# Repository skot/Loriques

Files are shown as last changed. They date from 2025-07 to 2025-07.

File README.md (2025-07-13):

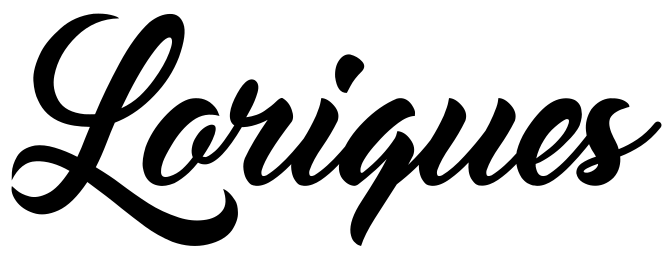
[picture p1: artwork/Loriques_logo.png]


Loriques is a solar powered Meshtastic LoRa gateway. *Warning: Loriques is very much a work in progress.*

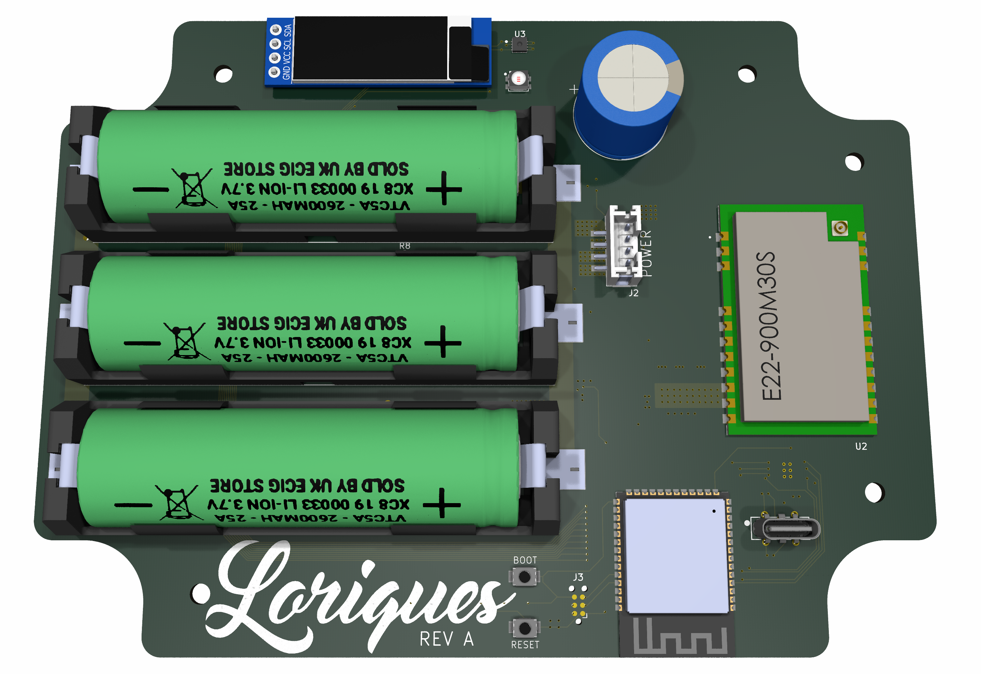
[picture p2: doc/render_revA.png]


- Designed to work with a small 6V solar panel. Like the [Voltaic 6 Watt Panel](https://voltaicsystems.com/6-watt-panel/)
- [EBYTE E22-900M30S](https://www.cdebyte.com/products/E22-900M30S/3) 30dBm LoRa tranciever
  - Untested; I picked this because it's in the Meshtastic supported LoRa ISM band, and it has one of the highest listed output power of LoRa modules.
  - Selecting a good high-gain antenna for this module is TBD.
- ESP32S3 WiFi and BLE SoC
- OLED Display
- Holders for three 18650 Lithium Ion batteries
- MCP73871 Solar charge controller
  - Optimized for solar charging and load sharing, but not a "true MPPT" controller. More info from [Adafruit](https://learn.adafruit.com/usb-dc-and-solar-lipoly-charger/design-notes)
- MAX17263 Battery fuel Guage
- HDC3020 Temperature and humidity sensor
  - This is helpful for monitoring how waterproof your outdoor enclosure is. 
- Very low noise, filtered 3.3V voltage regulator
- PCB designed to fit into the [Polycase ML-46F](https://www.polycase.com/ml-46f#ML-46F*15) Outdoor NEMA Enclosure
- ESP32 Firmware is **not** started yet!
  - There are some big challenges here, like getting the ESP32S3 and it's radios in, and out of a low power state.

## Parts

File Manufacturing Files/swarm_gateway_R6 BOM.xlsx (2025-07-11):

Qty | Part Name | PARTNO | Device | Value | Description
1 | A2 | W3012 | W3012 | W3012 | 900MHz Chip RF Antenna 902MHz ~ 928MHz 2dBi Solder Surface Mount
3 | B1 B2 B3 | 1042 | 18650_1042 | 18650_1042 | Battery Holder (Open) 18650 1 Cell SMD Tab
1 | IC11 | TCM310U | STM300_TCM300 | TCM310U | General ISM < 1GHz - Transceiver Module 902MHz Antenna Not Included Surface Mount
18 | C1 C2 C8 C9 C14 C15 C17 C20 C21 C26 C29 C30 C42 C43 C48 C50 C63 C23 | CL05B104KO5NNNC | CAP0402 | 0.1uF | 0402 Capacitor
1 | C25 | GRT155R61E474ME01D | CAP0402 | 0.47uF | 0402 Capacitor
8 | C40 C60 C69 C72 C73 C75 C76 C12 | GCM155R71H102KA37D | CAP0402 | 1nF | 0402 Capacitor
6 | C37 C39 C34 C35 C59 C61 | GRT155R61E105KE01D | CAP0402 | 1uF | 0402 Capacitor
2 | C33 C38 | CL10A105KA8NNNC | CAP0603 | 1uF | 0603 Capacitor
1 | C13 | 885012107013 | CAP0805 | 4.7uF | 0805 Capacitor
1 | C11 | CL05C100DB5NNNC | CAP0402 | 10pF C0G | 0402 Capacitor
4 | C3 C5 C6 C22 | GRM188R6YA106MA73D | CAP0603 | 10uF | 0603 Capacitor
4 | C41 C45 C46 C47 | CL31B106KOHNNWE | CAP1206 | 10uF | 1206 Capacitor
1 | C16 | 293D106X0010A2TE3 | CPOL_3216 | 10uF | Polarized SMD Capacitor 3126
4 | C4 C7 C18 C19 | CC0402FRNPO9BN220 | CAP0402 | 22pF | 0402 Capacitor
2 | C31 C44 | LMK212BBJ226MG-T | CAP0805 | 22uF | 0805 Capacitor
1 | C10 | C1005C0G1H470J050BA | CAP0402 | 47pF C0G | 0402 Capacitor
1 | C28 | C4532X5R1A476M280KA | CAP1812 | 47uF 10V | 1812 Capacitor
1 | C32 | C4532X5R0J107M280KA | CAP1812 | 100uF 6.3V | 1812 Capacitor
2 | C62 C64 | GRM32ER60J227ME05L | CAP1210 | 220uF | 1210 Capacitor
1 | C24 | CL05C681JB5NNNC | CAP0402 | 680pF C0G | 0402 Capacitor
1 | DISP1 | SAM1213-04-ND |  | SSW-104-01-T-S | 4 pin 0.1" female header
1 | C27 | 25PK4700MEFC16X25 | CPOL_16X27MM | 4700uF | 4700µF 25V Aluminum Electrolytic Capacitors Radial
1 | D1 | MBR120VLSFT1G | MBR120VLSF | MBR120VLSF | SOD-123F SMD Schottky Diode
2 | D2 D3 | SMAJ5.0A | SMAJ5.0A | SMAJ5.0A | 9.2V Clamp 43.5A Ipp Tvs Diode Surface Mount DO-214AC (SMA)
2 | FL2 FL3 | YFF31HC2A104MT000N | YFF31HC2A104MT000N | YFF31HC2A104MT000N | 0.1µF Feed Through Capacitor 100V 10A 1.5mOhm 1206 (3216 Metric), 4 PC Pad
1 | FL1 | YFF31HC2A105MT000N | YFF31HC2A105MT000N | YFF31HC2A105MT000N | Feed Through Capacitor 100V 5mOhm 1206 (3216 Metric), 4 PC Pad
1 | IC5 | CAT25160VI-GT3 | CAT25160VI-GT3 | CAT25160VI-GT3 | EEPROM Memory IC 16Kb (2K x 8) SPI 20MHz 8-SOIC
1 | IC3 | HDC2080DMBR | HDC2080 | HDC2080 | Humidity Temperature Sensor 0 ~ 100% RH I¬≤C ±2% RH 8s Surface Mount
1 | IC7 | LP38693MP-ADJ | LP38691-ADJ | LP38691-ADJ | LP38693-ADJ Voltage Regulator
1 | IC9 | LTC3113EDHD#TRPBF | LTC3113 | LTC3113 | Buck-Boost Switching Regulator IC Positive Adjustable 1.8V 1 Output 3A 16-WFDFN Exposed Pad
1 | IC10 | MAX17263LETD+T | MAX17263LETD+T | MAX17263LETD+T | Single/Multi-Cell Fuel Gauge with ModelGauge m5 EZ and Integrated LED Control
1 | IC2 | MCP73871-2CCI/ML | MCP73871 | MCP73871 | Microchip Li Battery Charge controller
1 | IC1 | MSP432P401RIPZR | MSP432 | MSP432P401R | ARM Cortex-M4F MSP432 Microcontroller IC 32-Bit 48MHz 256KB (256K x 8) FLASH 100-LQFP (14x14)
2 | IC6 IC8 | SN74LVC244ARGY | SN74LVC244A | SN74LVC244A | SN74LVC244A Buffer, Non-Inverting 2 Element 4 Bit per Element Push-Pull Output 20-VQFN (3.5x4.5)
1 | IC4 | TPS2013AD | TPS2013A | TPS2013A | IC 2.2A POWER DIST SWITCH 8-SOIC
3 | IC12 IC13 IC19 | TPS22975DSGR | TPS22975 | TPS22975 | TPS22975LOAD SWITCH N-CH 6A 8WSON
1 | IC14 | AT25QF641B-SHB-T | AT25QF641B-SHB-T | AT25QF641B-SHB-T | FLASH - NOR Memory IC 64Mb (8M x 8) SPI 104MHz 8-SOIC
1 | J2 | B-PH-SM4-TB(LF)(SN) | JST_4PIN | JST_4PIN | Connector Header Surface Mount 4 position 0.079" (2.00mm)
1 | J1 | B3B-PH-SM4-TB(LF)(SN) | JST_PH_3PIN | JST_PH_3PIN | Connector Header Surface Mount 3 position 0.079" (2.00mm)
1 | L1 | HCMA0703-2R2-R | HCMA0703-2R2-R | 2.2uH | 2.2µH Shielded Wirewound Inductor 8A 20mOhm Max Nonstandard
1 | L2 | LQM21PN4R7NGRD | LQM2MP_G0 | 4.7uH | 4.7µH Shielded Multilayer Inductor 800mA 288 mOhm Max 0805
1 | L3 | 742863160 | FERRITE_0603 | FERRITE | 0603 Ferrite bead
3 | LED0 LED1 LED2 | CLV1A-FKB-CK1VW1DE1BB7C3C3 | CLV1L-FKB | CLV1A-FKB | Red, Green, Blue (RGB) 622nm Red, 529nm Green, 469nm Blue LED Indication - Discrete 2V Red, 3.2V Green, 3.2V Blue 4-LCC (J-Lead)
1 | Q1 | FC-135R 32.7680KA-A3 | CRYSTALLF_GENERAL | 32kHz
1 | Q2 | FA-238 48.0000MB-K3 | FA-238-ALLEPSON_FA-238 | 48MHz
3 | R1 R21 R23 | RMCF0402ZT0R00 | RESISTOR0402-RES | 0 | 0402 Resistor
1 | R37 | RC0402FR-071K1L | RESISTOR0402-RES | 1.1k | 0402 Resistor
1 | R15 | RC0402FR-071K54L | RESISTOR0402-RES | 1.54k | 0402 Resistor
1 | R39 | CRCW04021M00FKEDC | RESISTOR0402-RES | 1M | 0402 Resistor
1 | R11 | RC0402FR-071KL | RESISTOR0402-RES | 1k | 0402 Resistor
1 | R3 | RMCF0402FT6K49 | RESISTOR0402-RES | 6.49k | 0402 Resistor
7 | R24 R25 R48 R49 R18 R19 R20 | RC0402FR-0710KL | RESISTOR0402-RES | 10k | 0402 Resistor
1 | R8 | ERT-J0EM103J | RESISTOR0402-RES | 10k NTC | 0402 Resistor
1 | R36 | PCS1206DR0100ET | RESISTOR1206 | 10m 0.5% | 1206 Resistor
6 | R16 R17 R26 R27 R28 R29 | CRGCQ0402J22R | RESISTOR0402-RES | 22 | 0402 Resistor
1 | R4 | ERJ-2RKF4702X | RESISTOR0402-RES | 47k | 0402 Resistor
1 | R7 | RC0402FR-0749K9L | RESISTOR0402-RES | 49.9k | 0402 Resistor
1 | R14 | RC0402FR-0769K8L | RESISTOR0402-RES | 69.8k | 0402 Resistor
1 | R2 | ERA-6AEB913V | RESISTOR0805-RES | 91K | 0.1%, 25ppm/C 0805 Resistor
6 | R5 R12 R13 R32 R33 R40 | RC0402FR-07100KL | RESISTOR0402-RES | 100k | 0402 Resistor
1 | R10 | RC0402FR-07113KL | RESISTOR0402-RES | 113k | 0402 Resistor
2 | R34 R35 | RMCF0402FT182K | RESISTOR0402-RES | 182k | 0402 Resistor
3 | R22 R30 R31 | CRGCQ0402F270R | RESISTOR0402-RES | 270 | 0402 Resistor
1 | R38 | RC0402FR-07330RL | RESISTOR0402-RES | 330 | 0402 Resistor
1 | R9 | RC0402JR-07330KL | RESISTOR0402-RES | 330k | 0402 Resistor
1 | R6 | RC0402FR-07825KL | RESISTOR0402-RES | 825k | 0402 Resistor
1 | S2 | MK24-A-2 | MK24-A-2 | MK24-A-2 | Molded Body Reed Switch SPST-NO 22 ~ 55AT Operate Range 1W 100mA (AC/DC) Surface Mount
1 | S1 | MS288-10F | MS288-10F | MS288-10F | RF Shield Frame 0.764" (19.40mm) X 1.134" (28.80mm) - Solder
1 | S1-2 | MS288-10C | MS288-10C | MS288-10C | Metal shield cover for MS288-10F. Snap onto S1
1 | IC15 | Swarm Tile - Consign | TILE_V3 | TILE_V3 | Swarm Tile V3 SMD Module - SweetSense consign

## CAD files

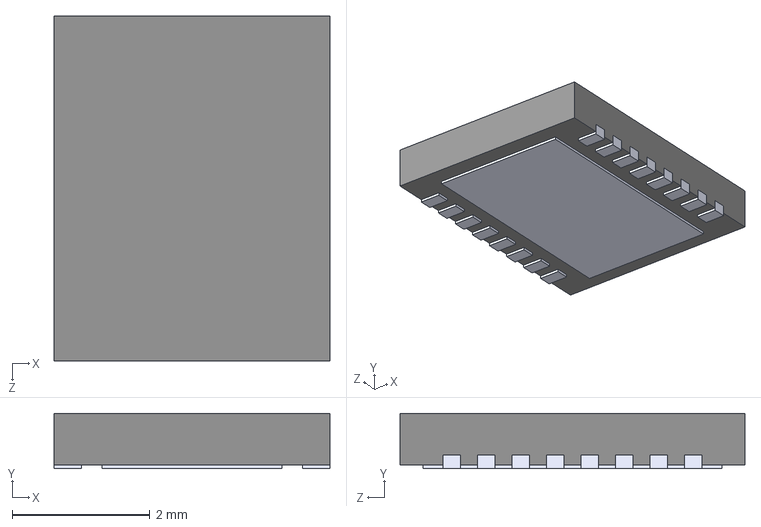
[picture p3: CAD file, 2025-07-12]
3d/LTC3113IDHD_TRPBF.step
4.00 x 0.8 x 5.00 mm

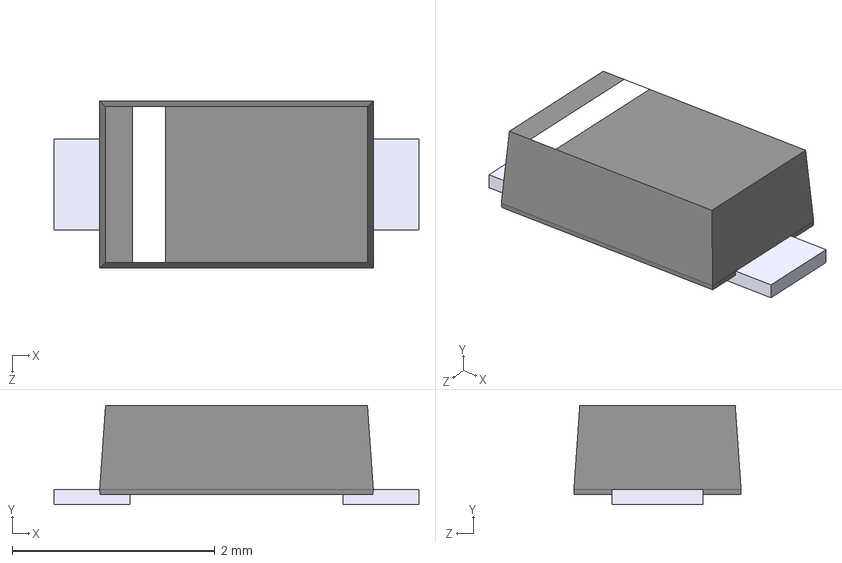
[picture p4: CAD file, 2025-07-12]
3d/MBR120VLSFT1G.step
3.60 x 0.98 x 1.65 mm

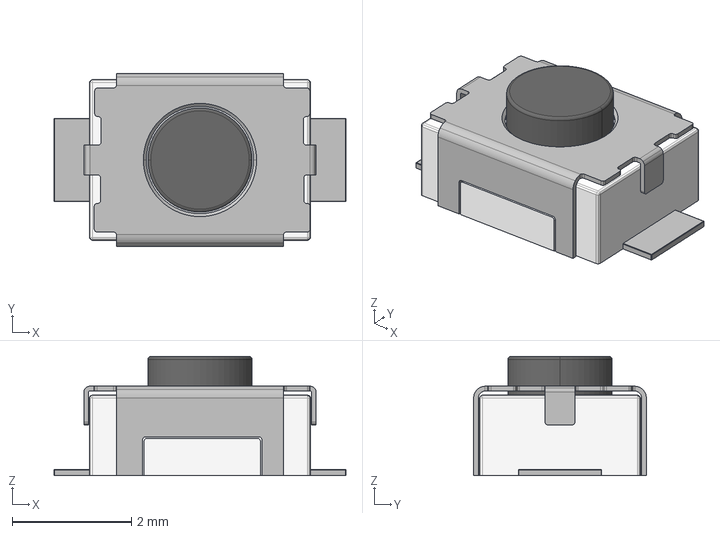
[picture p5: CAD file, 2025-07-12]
3d/CS1213AG-tr.stp
4.90 x 2.90 x 2.00 mm

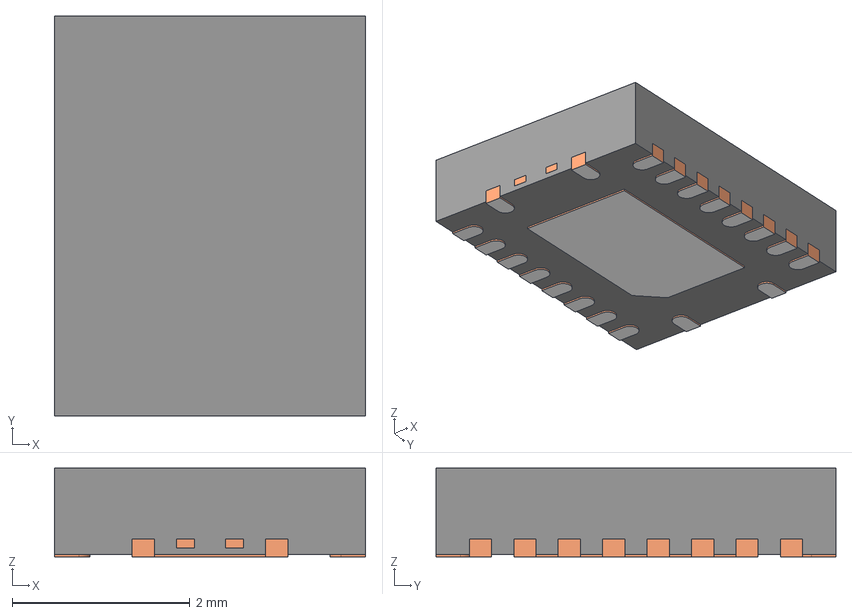
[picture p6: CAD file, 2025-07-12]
3d/RGY0020A.stp
3.50 x 4.50 x 1.00 mm
BODY-QFN
FRAME-RGY0020A
PIN1-ID

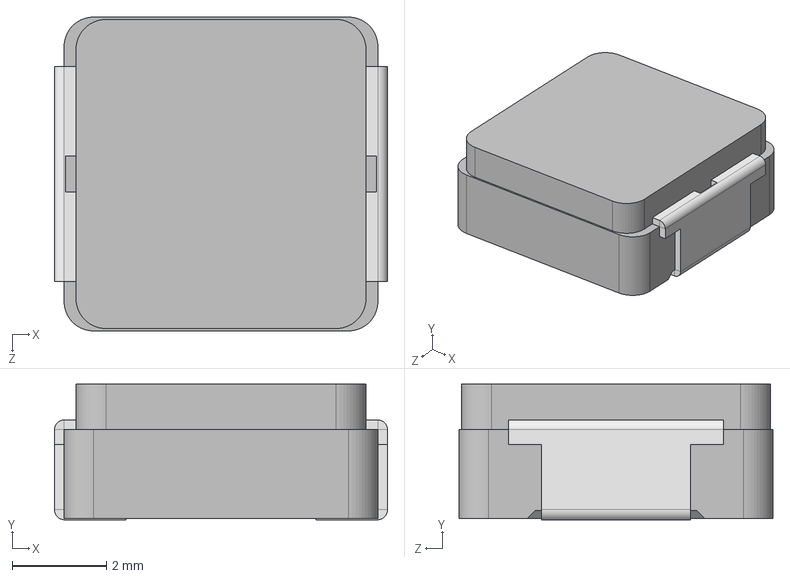
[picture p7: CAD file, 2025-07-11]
3d/IHLP2525CZ.step
7.08 x 2.88 x 6.67 mm

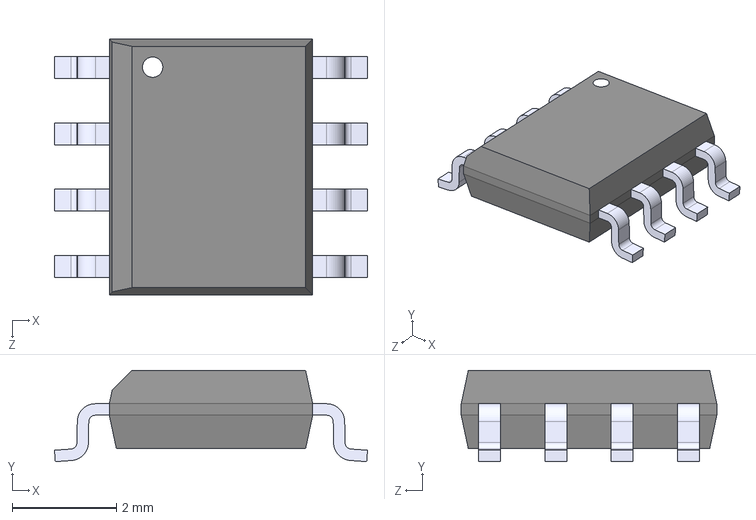
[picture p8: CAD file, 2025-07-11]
3d/TPS2013AD.step
6.00 x 1.75 x 4.90 mm

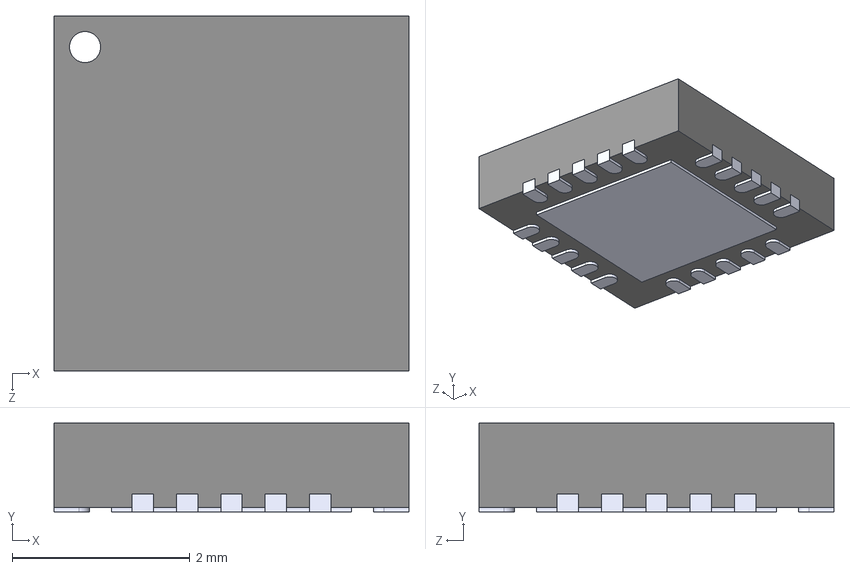
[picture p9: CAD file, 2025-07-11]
3d/ML.STEP
4.00 x 1.00 x 4.00 mm

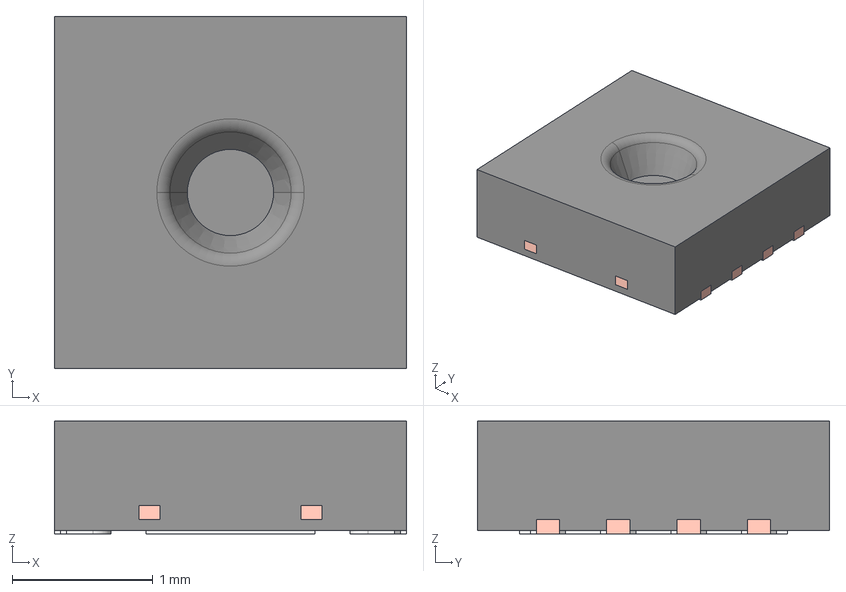
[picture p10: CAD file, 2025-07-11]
3d/DEF0008A.stp
2.50 x 2.50 x 0.8 mm
BODY-SON
FRAME-DEF0008A
PIN1-ID
SENSOR_AREA

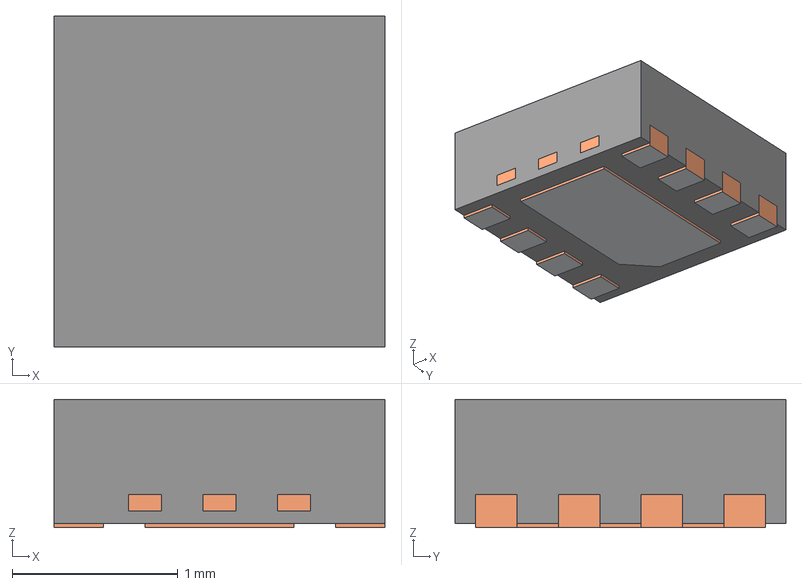
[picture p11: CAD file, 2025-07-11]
3d/DSG0008A.stp
2.00 x 2.00 x 0.775 mm
BODY-SON
FRAME-DSG0008A
PIN1-ID

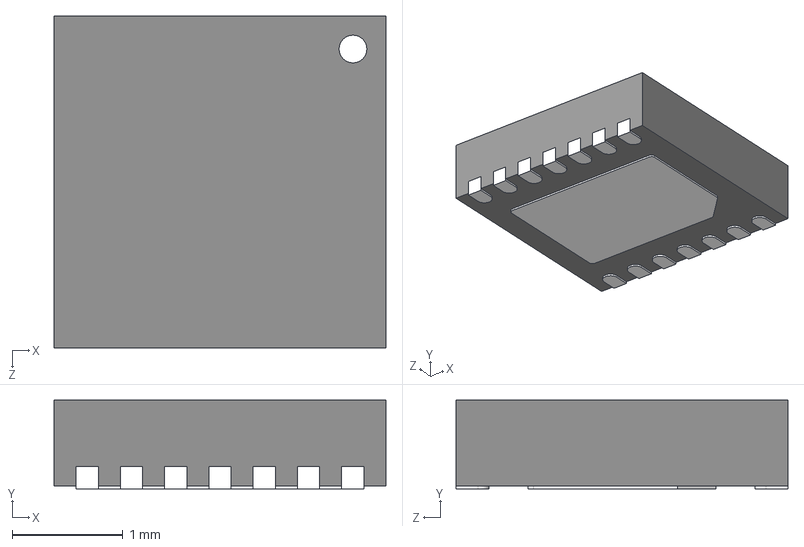
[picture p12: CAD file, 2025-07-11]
3d/SON40P300X300X80-15N.step
3.00 x 0.8 x 3.00 mm

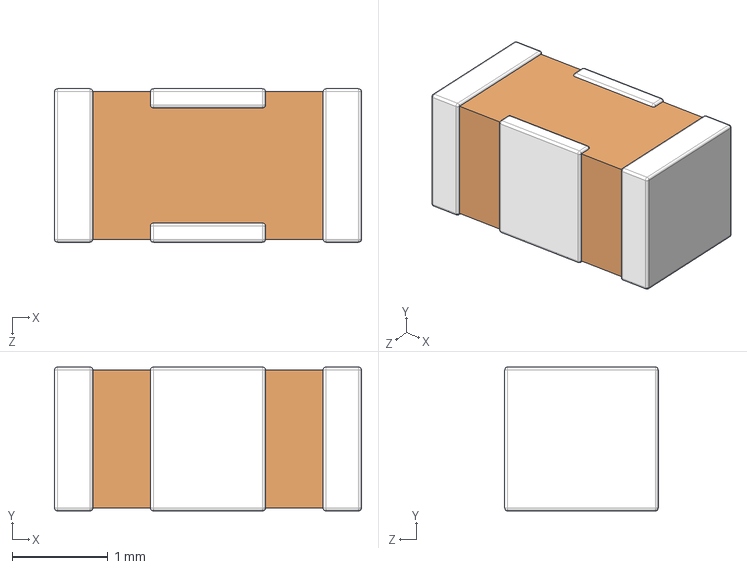
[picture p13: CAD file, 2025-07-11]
3d/YFF31HC2A105MT000N.step
3.20 x 1.50 x 1.60 mm

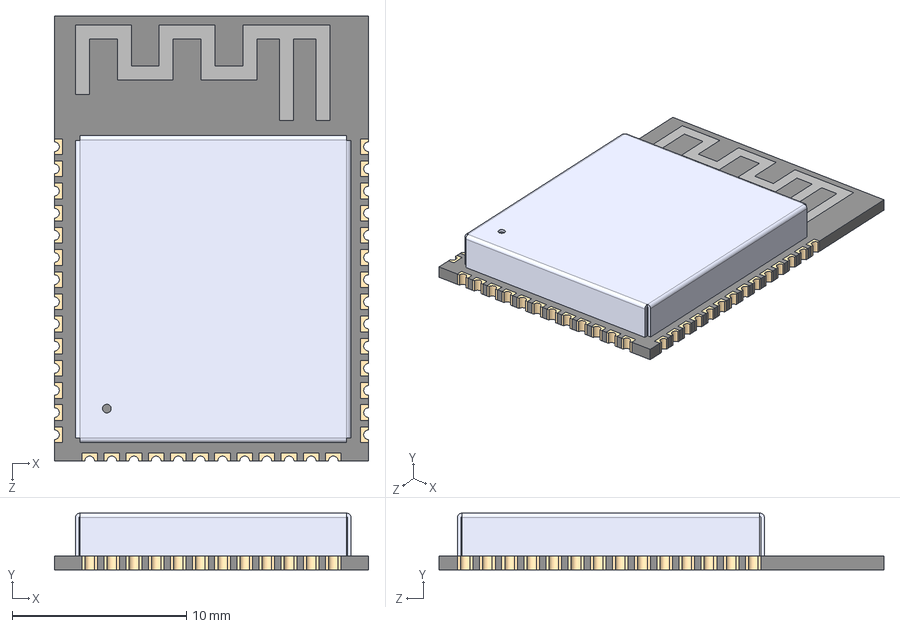
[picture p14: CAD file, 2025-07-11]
3d/ESP32-S3-WROOM-1-N8R2--3DModel-STEP-56544.STEP
18.0 x 3.25 x 25.5 mm

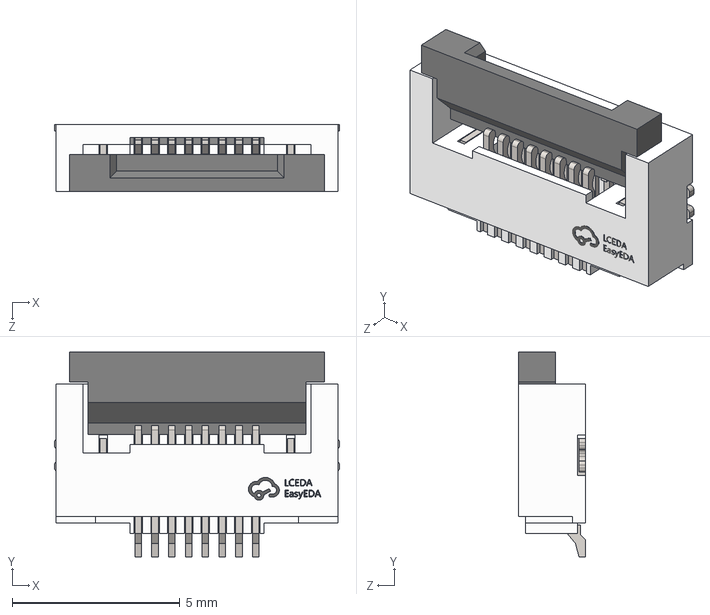
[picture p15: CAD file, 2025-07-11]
3d/FPC-SMD_P0.50-8P_FGS-XJ-H2.0.step
8.50 x 6.10 x 2.01 mm

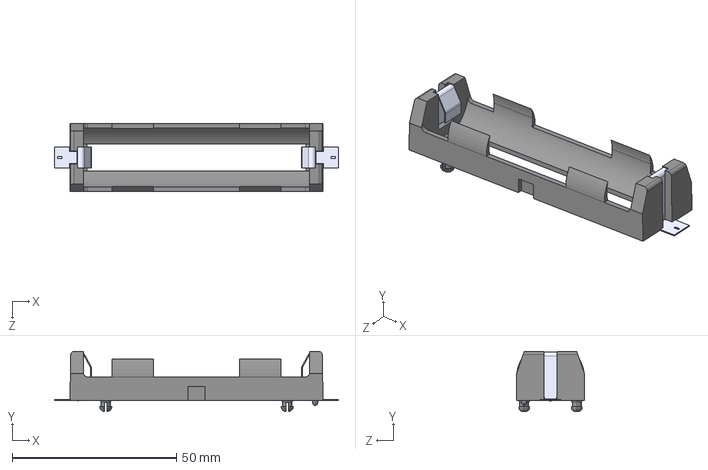
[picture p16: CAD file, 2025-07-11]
3d/1042.STEP
86.5 x 18.3 x 20.7 mm

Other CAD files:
3d/OLED_0.91_128x32.stp
3d/CLV1A-FKB.stp
3d/B3B-PH-SM4-TB.STEP
3d/B4B-PH-SM4-TB.STEP
3d/E22-900M30S.STEP
3d/HDC2080DMBR.STEP
3d/LP38693MP-ADJ_NOPB.step

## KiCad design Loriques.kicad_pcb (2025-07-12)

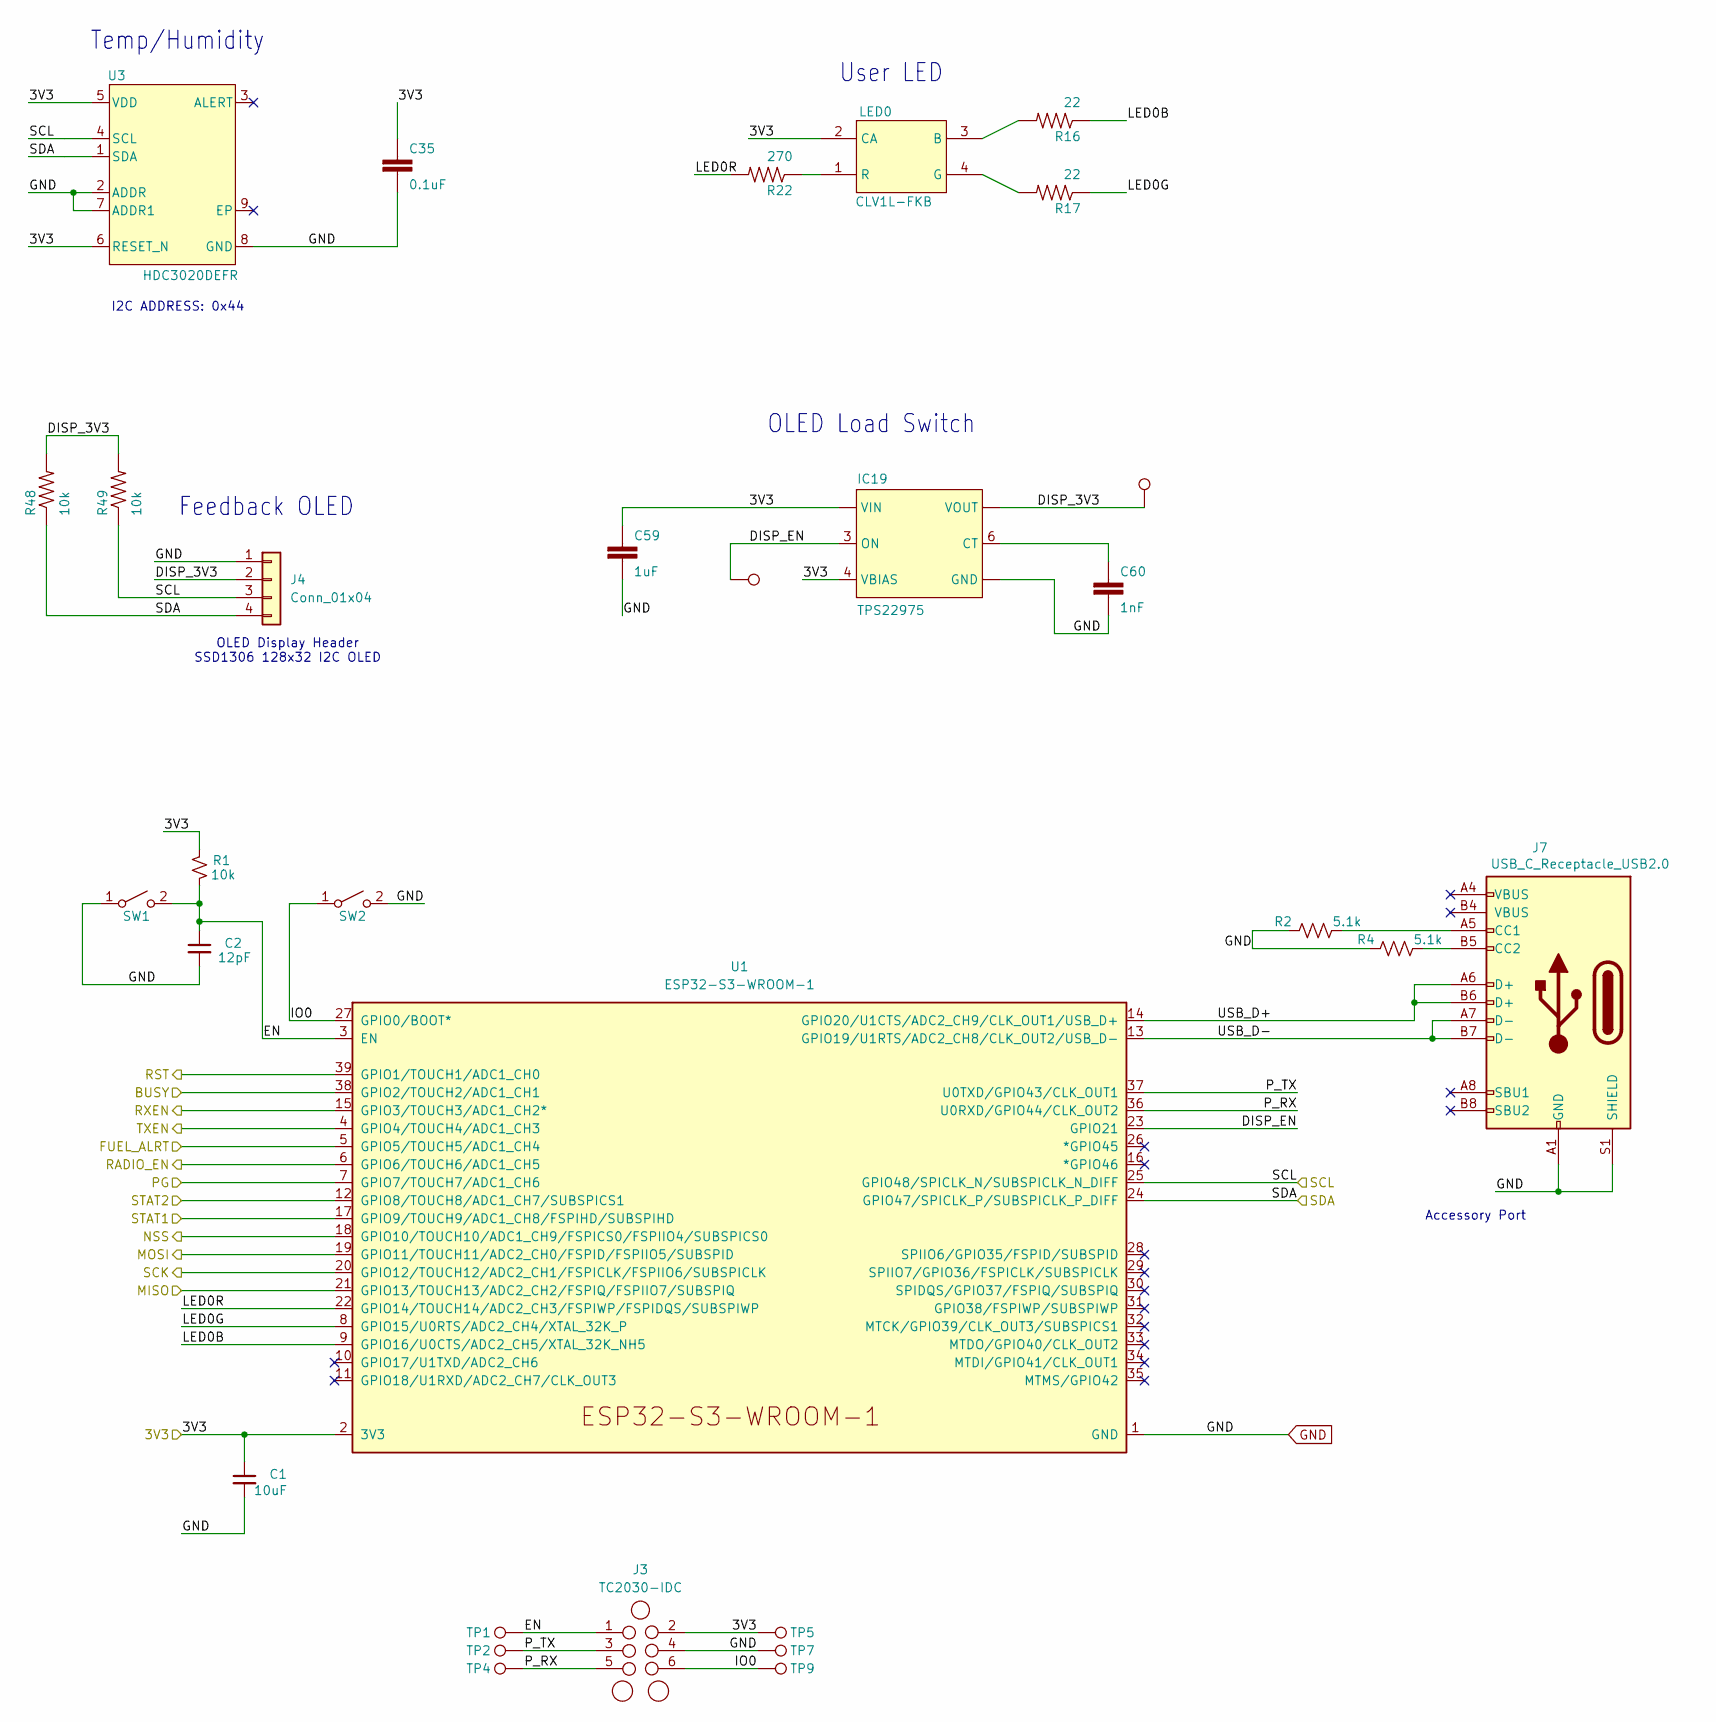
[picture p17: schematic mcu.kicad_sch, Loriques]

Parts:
C1: 10uF; C_0603_1608Metric; Voltage 25V; PARTNO GRM188R61E106KA73D
C2: 12pF; C_0402_1005Metric; Voltage 50V; PARTNO CC0402JRNPO9BN120
C35: 0.1uF; C_0402_1005Metric; PARTNO CL05B104KO5NNNC
C59: 1uF; C_0402_1005Metric; PARTNO GRT155R61E105KE01D
C60: 1nF; C_0402_1005Metric; PARTNO CC0402KRX7R8BB102
IC19: TPS22975; WSON8; PARTNO TPS22975DSGR
J3: TC2030-IDC; Tag-Connect_TC2030-IDC-NL_2x03_P1.27mm_Vertical
J4: Conn_01x04; PinHeader_1x04_P2.54mm_Vertical_shifted
J7: USB_C_Receptacle_USB2.0; CONN_12402032E202A_AMP; PARTNO 12402032E202A
LED0: CLV1L-FKB; PLCC140P350X320X210-4; PARTNO CLV1A-FKB-CK1VW1DE1BB7C3C3
R1: 10k; R_0402_1005Metric; PARTNO RC0402JR-0710KL
R2, R4: 5.1k; R_0402_1005Metric; PARTNO RMCF0402JT5K10; LCSC C25905
R16, R17: 22; R_0402_1005Metric; PARTNO CRGCQ0402J22R
R22: 270; R_0402_1005Metric; PARTNO CRGCQ0402F270R
R48, R49: 10k; R_0402_1005Metric
SW1: SWITCH-SPST; SW_CS1213AGF260_CRS; PARTNO CS1213AGF260; LCSC C5578986
SW2: SWITCH-SPST; SW_CS1213AGF260_CRS; PARTNO CS1213AGF260
S_3V1: TEST-POINT3X5; TestPoint_Pad_D1.5mm
TP1, TP2, TP4, TP5, TP7, TP9: TestPoint; TestPoint_Pad_D1.5mm
TP3: TEST-POINT3X5; TestPoint_Pad_D1.5mm
U1: ESP32-S3-WROOM-1; PARTNO ESP32-S3-WROOM-1-N16R8
U3: HDC3020DEFR; DEF0008A-IPC_A; PARTNO HDC3020DEFR

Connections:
/FUEL: U1.5 (GPIO5/TOUCH5/ADC1_CH4); also elsewhere on the board
/MCU/3V3: C1.1, C35.1, C59.1, IC19.1 (VIN), IC19.2 (VIN), IC19.4 (VBIAS), J3.2, LED0.2 (CA), R1.2, TP5.1, U1.2 (3V3), U3.5 (VDD), U3.6 (RESET_N); also elsewhere on the board
/MCU/DISP_3V3: IC19.7 (VOUT), IC19.8 (VOUT), J4.2, R48.2, R49.2, S_3V1.1
/MCU/DISP_EN: IC19.3 (ON), TP3.1, U1.23 (GPIO21)
/MCU/EN: C2.1, J3.1, R1.1, SW1.2 (B), TP1.1, U1.3 (EN)
/MCU/IO0: J3.6, SW2.1 (A), TP9.1, U1.27 (GPIO0/BOOT*)
/MCU/LED0B: R16.1, U1.9 (GPIO16/U0CTS/ADC2_CH5/XTAL_32K_NH5)
/MCU/LED0G: R17.1, U1.8 (GPIO15/U0RTS/ADC2_CH4/XTAL_32K_P)
/MCU/LED0R: R22.2, U1.22 (GPIO14/TOUCH14/ADC2_CH3/FSPIWP/FSPIDQS/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)
/MCU/PG: U1.7 (GPIO7/TOUCH7/ADC1_CH6); also elsewhere on the board
/MCU/P_RX: J3.5, TP4.1, U1.36 (U0RXD/GPIO44/CLK_OUT2)
/MCU/P_TX: J3.3, TP2.1, U1.37 (U0TXD/GPIO43/CLK_OUT1)
/MCU/RADIO_EN: U1.6 (GPIO6/TOUCH6/ADC1_CH5); also elsewhere on the board
/MCU/STAT1: U1.17 (GPIO9/TOUCH9/ADC1_CH8/FSPIHD/SUBSPIHD); also elsewhere on the board
/MCU/STAT2: U1.12 (GPIO8/TOUCH8/ADC1_CH7/SUBSPICS1); also elsewhere on the board
/MCU/USB_D+: J7.A6 (D+), J7.B6 (D+), U1.14 (GPIO20/U1CTS/ADC2_CH9/CLK_OUT1/USB_D+)
/MCU/USB_D-: J7.A7 (D-), J7.B7 (D-), U1.13 (GPIO19/U1RTS/ADC2_CH8/CLK_OUT2/USB_D-)
/Radio/BUSY_MCU: U1.38 (GPIO2/TOUCH2/ADC1_CH1); also elsewhere on the board
/Radio/MISO_MCU: U1.21 (GPIO13/TOUCH13/ADC2_CH2/FSPIQ/FSPIIO7/S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); also elsewhere on the board
/Radio/MOSI_MCU: U1.19 (GPIO11/TOUCH11/ADC2_CH0/FSPID/FSPIIO5/S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); also elsewhere on the board
/Radio/NSS_MCU: U1.18 (GPIO10/TOUCH10/ADC1_CH9/FSPICS0/FSPIIO4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); also elsewhere on the board
/Radio/RST_MCU: U1.39 (GPIO1/TOUCH1/ADC1_CH0); also elsewhere on the board
/Radio/RXEN_MCU: U1.15 (GPIO3/TOUCH3/ADC1_CH2*); also elsewhere on the board
/Radio/SCK_MCU: U1.20 (GPIO12/TOUCH12/ADC2_CH1/FSPICLK/FSPIIO6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); also elsewhere on the board
/Radio/TXEN_MCU: U1.4 (GPIO4/TOUCH4/ADC1_CH3); also elsewhere on the board
/SCL: J4.3, R49.1, U1.25 (GPIO48/SPICLK_N/SUBSPICLK_N_DIFF), U3.4 (SCL); also elsewhere on the board
/SDA: J4.4, R48.1, U1.24 (GPIO47/SPICLK_P/SUBSPICLK_P_DIFF), U3.1 (SDA); also elsewhere on the board
GND: C1.2, C2.2, C35.2, C59.2, C60.2, IC19.5 (GND), IC19.PP (GND), J3.4, J4.1, J7.A1 (GND), J7.B1 (GND), J7.S1 (SHIELD), R2.1, R4.1, SW1.1 (A), SW2.2 (B), TP7.1, U1.1 (GND), U1.40 (GND), U1.41 (GND), U3.2 (ADDR), U3.7 (ADDR1), U3.8 (GND); also elsewhere on the board
unnamed: C60.1, IC19.6 (CT)
unnamed: J7.A5 (CC1), R2.2
unnamed: J7.B5 (CC2), R4.2
unnamed: LED0.3 (B), R16.2
unnamed: LED0.4 (G), R17.2
unnamed: LED0.1 (R), R22.1

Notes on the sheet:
Temp/Humidity
Accessory Port
Feedback OLED
OLED Load Switch
OLED Display Header SSD1306 128x32 I2C OLED
User LED
I2C ADDRESS: 0x44

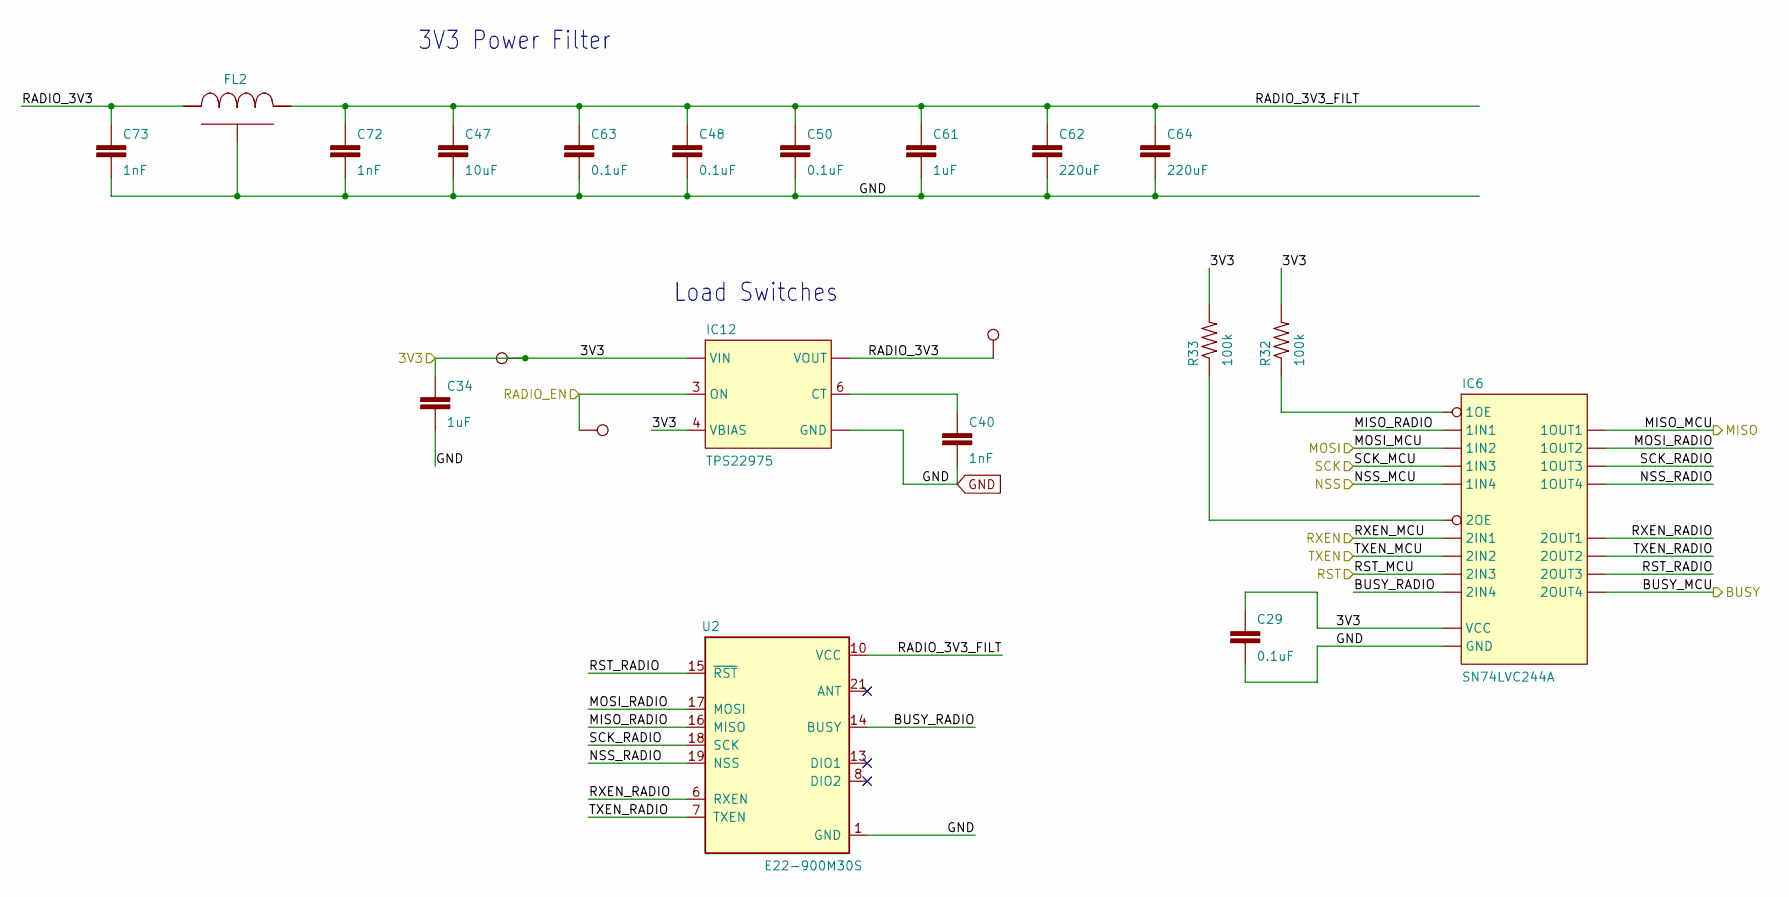
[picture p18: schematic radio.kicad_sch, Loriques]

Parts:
C29, C48, C50, C63: 0.1uF; C_0402_1005Metric; PARTNO CL05A104KA5NNNC
C34, C61: 1uF; C_0402_1005Metric; PARTNO GRT155R61E105KE01D
C40, C72, C73: 1nF; C_0402_1005Metric; PARTNO CC0402KRX7R8BB102
C47: 10uF; C_1206_3216Metric; PARTNO CL31B106KOHNNWE
C62, C64: 220uF; C_1210_3225Metric; PARTNO GRM32ER60J227ME05L
FL2: YFF31HC2A104MT000N; PARTNO YFF31HC2A105MT000N
IC6: SN74LVC244A; R-PVQFN-N20
IC12: TPS22975; WSON8; PARTNO TPS22975DSGR
R32, R33: 100k; R_0402_1005Metric; PARTNO RC0402FR-07100KL
S_3V3: TEST-POINT3X5; TestPoint_Pad_D1.5mm
TP6, TP8: TEST-POINT3X5; TestPoint_Pad_D1.5mm
U2: E22-900M30S

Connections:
/MCU/3V3: C29.1, C34.1, IC6.20 (VCC), IC12.1 (VIN), IC12.2 (VIN), IC12.4 (VBIAS), R32.2, R33.2, TP6.1; also elsewhere on the board
/MCU/RADIO_EN: IC12.3 (ON), TP8.1; also elsewhere on the board
/Radio/BUSY_MCU: IC6.3 (2OUT4); also elsewhere on the board
/Radio/BUSY_RADIO: IC6.17 (2IN4), U2.14 (BUSY)
/Radio/MISO_MCU: IC6.18 (1OUT1); also elsewhere on the board
/Radio/MISO_RADIO: IC6.2 (1IN1), U2.16 (MISO)
/Radio/MOSI_MCU: IC6.4 (1IN2); also elsewhere on the board
/Radio/MOSI_RADIO: IC6.16 (1OUT2), U2.17 (MOSI)
/Radio/NSS_MCU: IC6.8 (1IN4); also elsewhere on the board
/Radio/NSS_RADIO: IC6.12 (1OUT4), U2.19 (NSS)
/Radio/RADIO_3V3: C73.1, FL2.1, IC12.7 (VOUT), IC12.8 (VOUT), S_3V3.1
/Radio/RST_MCU: IC6.15 (2IN3); also elsewhere on the board
/Radio/RST_RADIO: IC6.5 (2OUT3), U2.15 (~RST)
/Radio/RXEN_MCU: IC6.11 (2IN1); also elsewhere on the board
/Radio/RXEN_RADIO: IC6.9 (2OUT1), U2.6 (RXEN)
/Radio/SCK_MCU: IC6.6 (1IN3); also elsewhere on the board
/Radio/SCK_RADIO: IC6.14 (1OUT3), U2.18 (SCK)
/Radio/TXEN_MCU: IC6.13 (2IN2); also elsewhere on the board
/Radio/TXEN_RADIO: IC6.7 (2OUT2), U2.7 (TXEN)
GND: C29.2, C34.2, C40.2, C47.2, C48.2, C50.2, C61.2, C62.2, C63.2, C64.2, C72.2, C73.2, FL2.GND, IC6.10 (GND), IC6.21 (GND), IC12.5 (GND), IC12.PP (GND), U2.1 (GND), U2.2 (GND), U2.3 (GND), U2.4 (GND), U2.5 (GND), U2.11 (GND), U2.12 (GND), U2.20 (GND), U2.22 (GND); also elsewhere on the board
unnamed: IC6.1 (1OE), R32.1
unnamed: IC6.19 (2OE), R33.1
unnamed: C40.1, IC12.6 (CT)
VCC: C47.1, C48.1, C50.1, C61.1, C62.1, C63.1, C64.1, C72.1, FL2.3 (2), U2.9 (VCC), U2.10 (VCC)

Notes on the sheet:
3V3 Power Filter
Load Switches

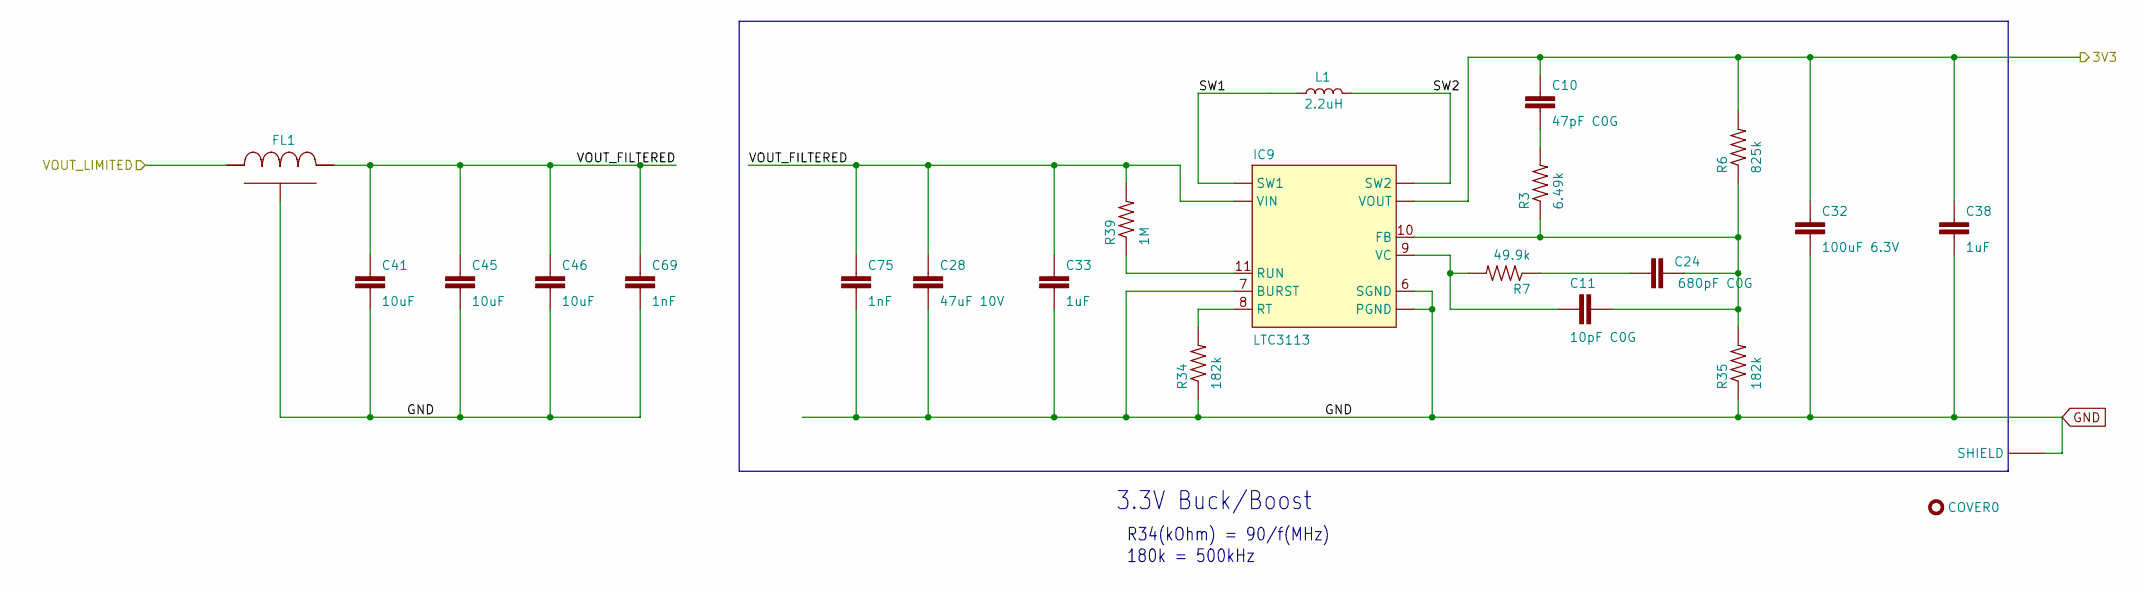
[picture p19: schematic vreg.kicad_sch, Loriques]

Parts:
C10: 47pF C0G; C_0402_1005Metric; PARTNO C1005C0G1H470J050BA
C11: 10pF C0G; C_0402_1005Metric; PARTNO CL05C100DB5NNNC
C24: 680pF C0G; C_0402_1005Metric; PARTNO CL05C681JB5NNNC
C28: 47uF 10V; C_1812_4532Metric; PARTNO C4532X5R1A476M280KA
C32: 100uF 6.3V; C_1812_4532Metric; PARTNO C4532X5R0J107M280KA
C33, C38: 1uF; C_0603_1608Metric; PARTNO CL10A105KA8NNNC
C41, C45, C46: 10uF; C_1206_3216Metric; PARTNO CL31B106KOHNNWE
C69, C75: 1nF; C_0402_1005Metric; PARTNO CC0402KRX7R8BB102
COVER0: BULLET; NOTHING; PARTNO MS288-10C
FL1: YFF31HC2A104MT000N; PARTNO YFF31HC2A105MT000N
IC9: LTC3113; SON50P400X500X80-17T244X434N; PARTNO LTC3113IDHD#TRPBF
L1: 2.2uH; IND_IHLP-2525CZ_VIS; PARTNO IHLP2525CZER2R2MA1
R3: 6.49k; R_0402_1005Metric; PARTNO RMCF0402FT6K49
R6: 825k; R_0402_1005Metric; PARTNO RC0402FR-07825KL
R7: 49.9k; R_0402_1005Metric; PARTNO RC0402FR-0749K9L
R34: 182k; R_0402_1005Metric; PARTNO ERJ-2RKF1823X
R35: 182k; R_0402_1005Metric; PARTNO RMCF0402FT182K
R39: 1M; R_0402_1005Metric; PARTNO CRCW04021M00FKEDC
S1: MS288-10F

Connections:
/MCU/3V3: C10.1, C32.1, C38.1, IC9.1 (VOUT), IC9.2 (VOUT), R6.2; also elsewhere on the board
/Power Input/VOUT_LIMITED: FL1.1; also elsewhere on the board
/Voltage Regulator/SW1: IC9.12 (SW1), IC9.13 (SW1), IC9.14 (SW1), L1.1
/Voltage Regulator/SW2: IC9.15 (SW2), IC9.16 (SW2), L1.2
/Voltage Regulator/VOUT_FILTERED: C28.1, C33.1, C41.1, C45.1, C46.1, C69.1, C75.1, FL1.3 (2), IC9.3 (VIN), IC9.4 (VIN), IC9.5 (VIN), R39.2
GND: C28.2, C32.2, C33.2, C38.2, C41.2, C45.2, C46.2, C69.2, C75.2, FL1.GND, IC9.6 (SGND), IC9.7 (BURST), IC9.17 (PGND), R34.1, R35.1, S1.1 (SHIELD); also elsewhere on the board
unnamed: C10.2, R3.2
unnamed: C24.1, R7.1
unnamed: C11.2, C24.2, IC9.10 (FB), R3.1, R6.1, R35.2
unnamed: IC9.8 (RT), R34.2
unnamed: IC9.11 (RUN), R39.1
unnamed: C11.1, IC9.9 (VC), R7.2

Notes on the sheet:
180k = 500kHz
R34(kOhm) = 90/f(MHz)
3.3V Buck/Boost

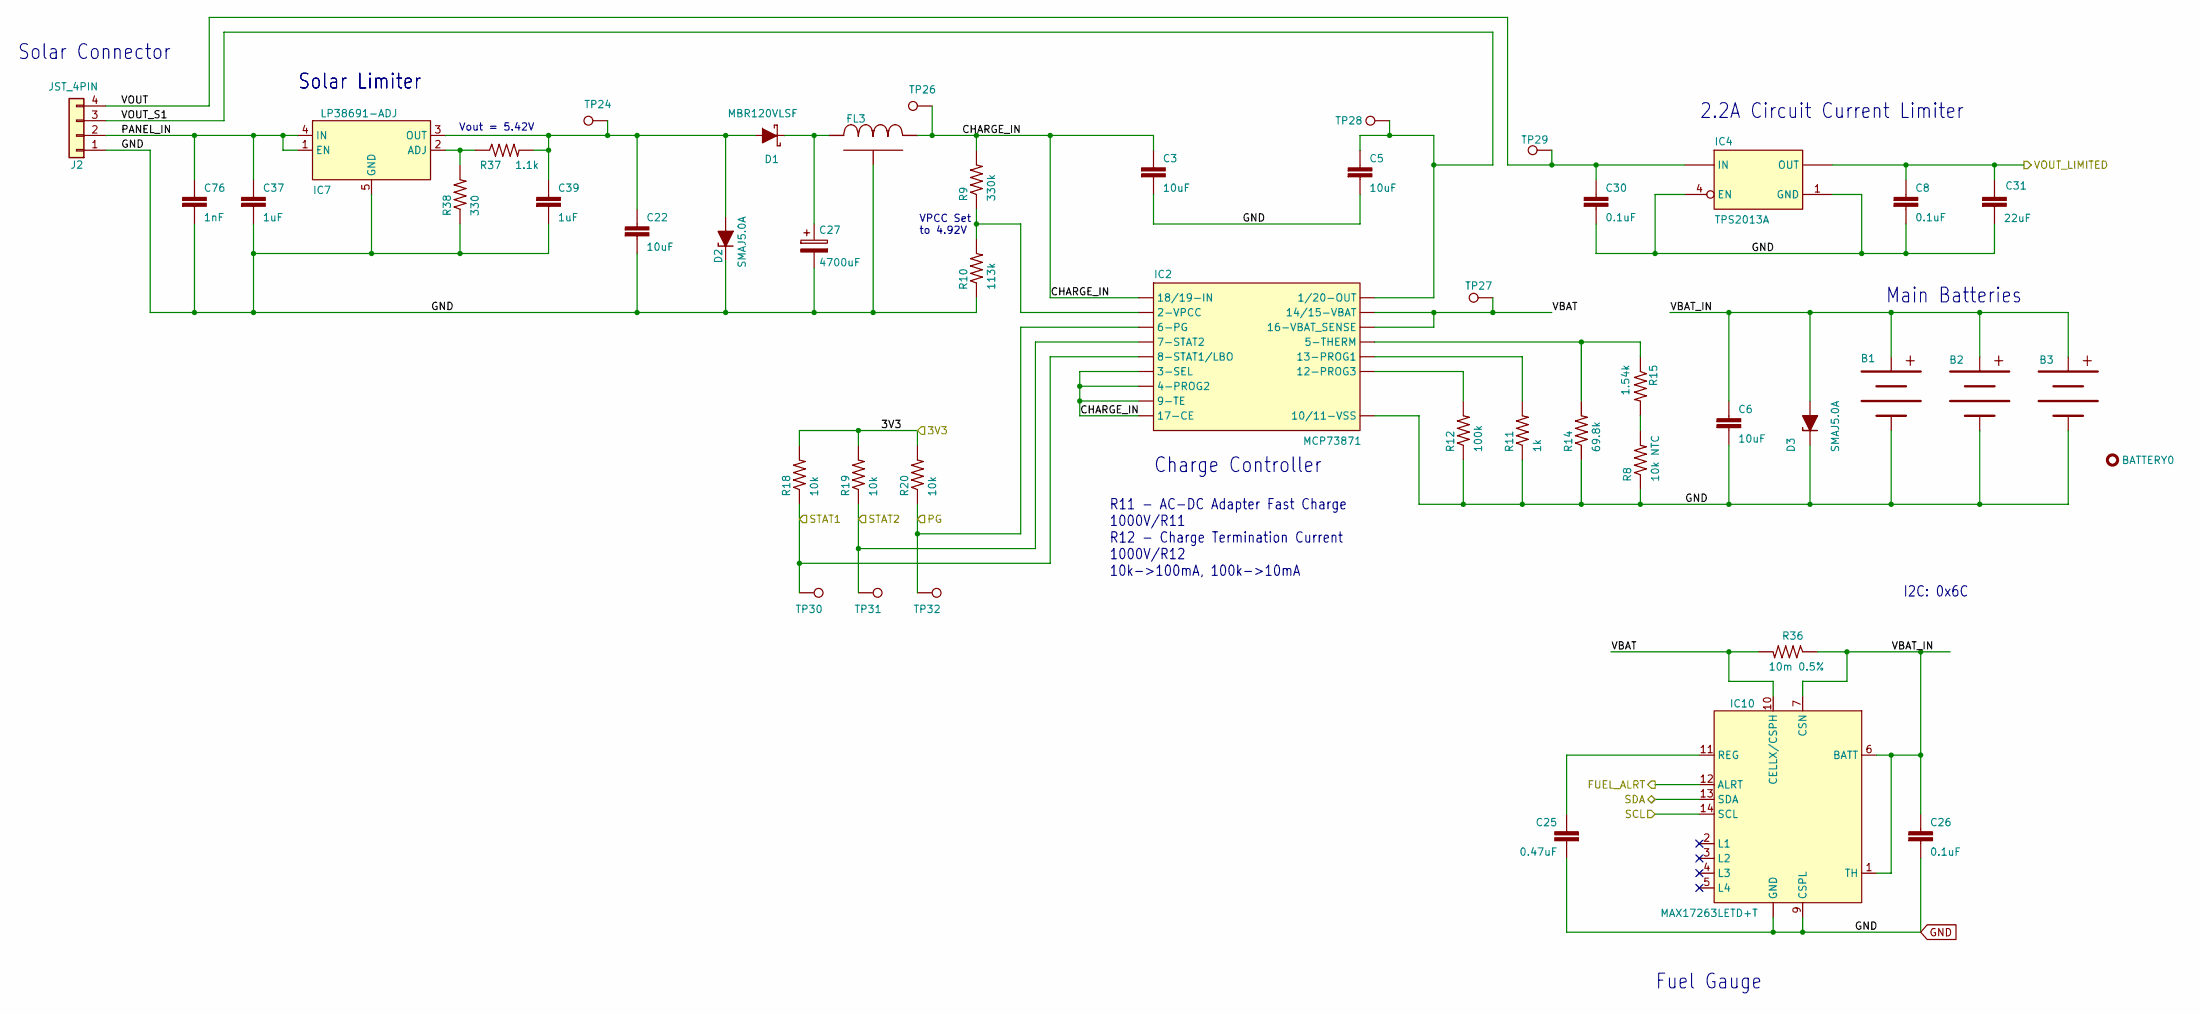
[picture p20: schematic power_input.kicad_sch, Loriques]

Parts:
B1, B2, B3: 18650_1042; 1042
BATTERY0: BULLET; NOTHING
C3, C5, C6, C22: 10uF; C_0603_1608Metric; PARTNO GRM188R6YA106MA73D
C8, C26, C30: 0.1uF; C_0402_1005Metric; PARTNO CL05A104KA5NNNC
C25: 0.47uF; C_0402_1005Metric; PARTNO GRT155R61E474ME01D
C27: 4700uF; CP_Radial_D16.0mm_P7.50mm; PARTNO 25PK4700MEFC16X25
C31: 22uF; C_0805_2012Metric; PARTNO GRM21BR61E226ME44L
C37, C39: 1uF; C_0402_1005Metric; PARTNO C1005X5R1V105K050BE
C76: 1nF; C_0402_1005Metric; PARTNO CC0402KRX7R8BB102
D1: MBR120VLSF; SOD−123FL; PARTNO MBR120VLSFT1G
D2, D3: SMAJ5.0A; D_SMA; PARTNO SMAJ5.0A
FL3: YFF31HC2A104MT000N; PARTNO YFF31HC2A105MT000N
IC2: MCP73871; QFN20-ML_4X4MM; PARTNO MCP73871-2CCI/ML
IC4: TPS2013A; R-PDSO-G8_NOPAD; PARTNO TPS2013AD
IC7: LP38691-ADJ; SOT-223-5; PARTNO LP38693MP-ADJ/NOPB
IC10: MAX17263LETD+T; SON40P300X300X80-15T170X230N; PARTNO MAX17263LETD+T
J2: JST_4PIN; JST-PH-4-SMT; PARTNO B4B-PH-SM4-TB
R8: 10k NTC; R_0402_1005Metric; PARTNO ERT-J0EM103J
R9: 330k; R_0402_1005Metric; PARTNO RC0402JR-07330KL
R10: 113k; R_0402_1005Metric; PARTNO RC0402FR-07113KL
R11: 1k; R_0402_1005Metric; PARTNO RC0402FR-071KL
R12: 100k; R_0402_1005Metric; PARTNO RC0402FR-07100KL
R14: 69.8k; R_0402_1005Metric; PARTNO RC0402FR-0769K8L
R15: 1.54k; R_0402_1005Metric; PARTNO RC0402FR-071K54L
R18, R19, R20: 10k; R_0402_1005Metric; PARTNO RC0402FR-0710KL
R36: 10m 0.5%; R_1206_3216Metric; PARTNO PCS1206DR0100ET
R37: 1.1k; R_0402_1005Metric; PARTNO RC0402FR-071K1L
R38: 330; R_0402_1005Metric; PARTNO RC0402FR-07330RL
TP24, TP26, TP27, TP28, TP29, TP30, TP31, TP32: TEST-POINT3X5; TestPoint_Pad_D1.5mm

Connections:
/FUEL: IC10.12 (ALRT); also elsewhere on the board
/MCU/3V3: R18.2, R19.2, R20.2; also elsewhere on the board
/MCU/PG: IC2.6 (6-PG), R20.1, TP32.1; also elsewhere on the board
/MCU/STAT1: IC2.8 (8-STAT1/LBO), R18.1, TP30.1; also elsewhere on the board
/MCU/STAT2: IC2.7 (7-STAT2), R19.1, TP31.1; also elsewhere on the board
/Power Input/CHARGE_IN: C3.1, FL3.3 (2), IC2.3 (3-SEL), IC2.4 (4-PROG2), IC2.9 (9-TE), IC2.17 (17-CE), IC2.18 (18/19-IN), IC2.19 (18/19-IN), R9.2, TP26.1
/Power Input/PANEL_IN: C37.1, C76.1, IC7.1 (EN), IC7.4 (IN), J2.2
/Power Input/VBAT: IC2.14 (14/15-VBAT), IC2.15 (14/15-VBAT), IC2.16 (16-VBAT_SENSE), IC10.10 (CELLX/CSPH), R36.2, TP27.1
/Power Input/VBAT_IN: B1.+, B2.+, B3.+, C6.1, C26.1, D3.2 (A), IC10.1 (TH), IC10.6 (BATT), IC10.7 (CSN), R36.1
/Power Input/VOUT: C30.1, IC4.2 (IN), IC4.3 (IN), J2.4, TP29.1
/Power Input/VOUT_LIMITED: C8.1, C31.1, IC4.5 (OUT), IC4.6 (OUT), IC4.7 (OUT), IC4.8 (OUT); also elsewhere on the board
/Power Input/VOUT_S1: C5.1, IC2.1 (1/20-OUT), IC2.20 (1/20-OUT), J2.3, TP28.1
/SCL: IC10.14 (SCL); also elsewhere on the board
/SDA: IC10.13 (SDA); also elsewhere on the board
GND: B1.-, B2.-, B3.-, C3.2, C5.2, C6.2, C8.2, C22.2, C25.2, C26.2, C27.2, C30.2, C31.2, C37.2, C39.2, C76.2, D2.1 (K), D3.1 (K), FL3.GND, IC2.10 (10/11-VSS), IC2.11 (10/11-VSS), IC2.EP (10/11-VSS), IC4.1 (GND), IC4.4 (EN), IC7.5 (GND), IC10.8 (GND), IC10.9 (CSPL), IC10.15 (GND), J2.1, R8.1, R10.1, R11.1, R12.1, R14.1, R38.1; also elsewhere on the board
unnamed: C27.1, D1.K, FL3.1
unnamed: C22.1, C39.1, D1.A, D2.2 (A), IC7.3 (OUT), R37.2, TP24.1
unnamed: IC2.2 (2-VPCC), R9.1, R10.2
unnamed: IC2.5 (5-THERM), R14.2, R15.1
unnamed: IC2.12 (12-PROG3), R12.2
unnamed: IC2.13 (13-PROG1), R11.2
unnamed: IC7.2 (ADJ), R37.1, R38.2
unnamed: C25.1, IC10.11 (REG)
unnamed: R8.2, R15.2

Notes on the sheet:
Vout = 5.42V
Solar Connector
Fuel Gauge
2.2A Circuit Current Limiter
R11 - AC-DC Adapter Fast Charge 1000V/R11 R12 - Charge Termination Current 1000V/R12 10k->100mA, 100k->10mA
I2C: 0x6C
Solar Limiter
Charge Controller
VPCC Set to 4.92V
Main Batteries

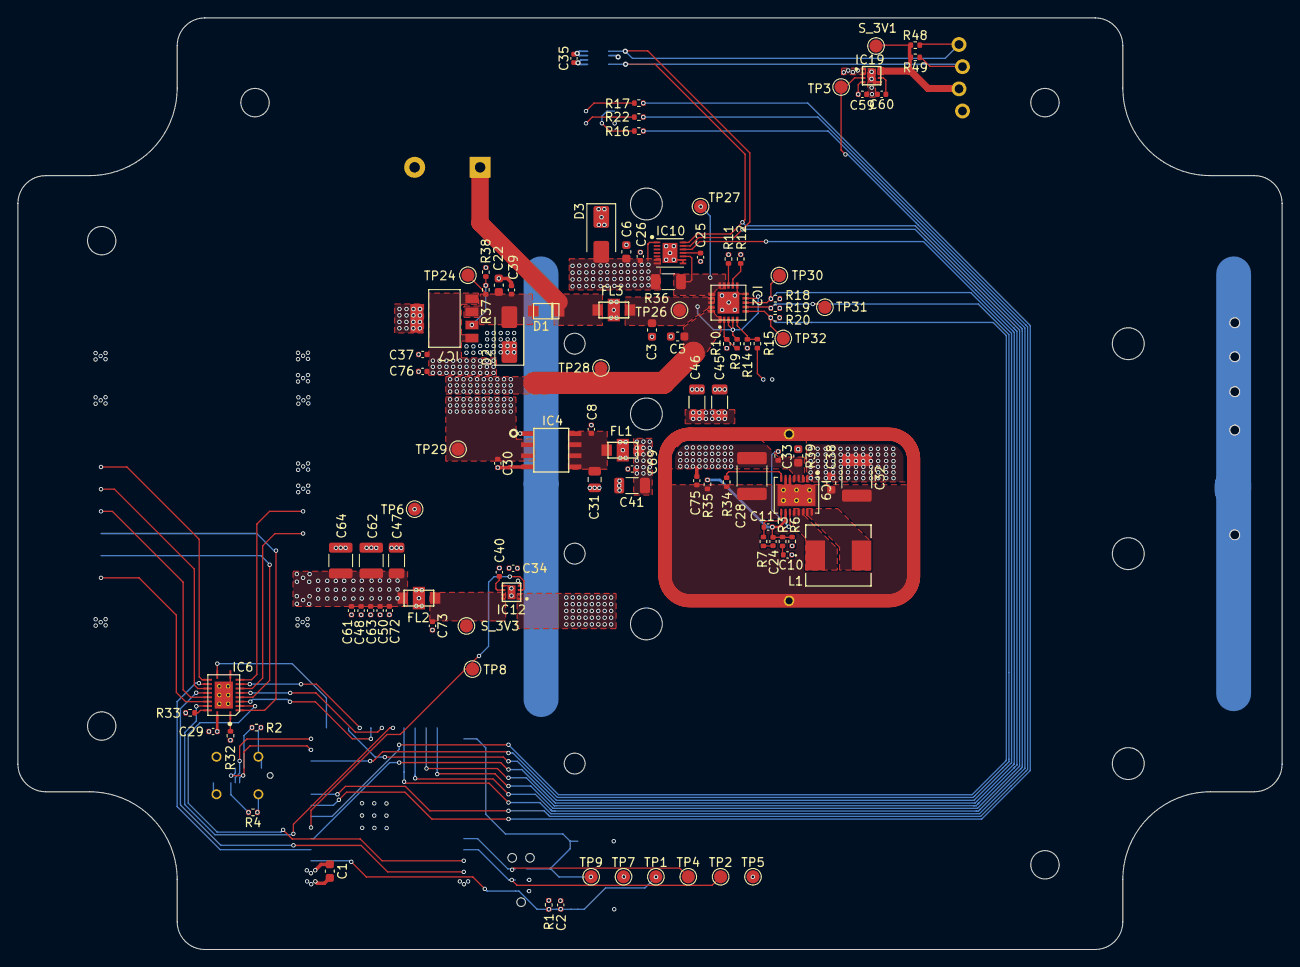
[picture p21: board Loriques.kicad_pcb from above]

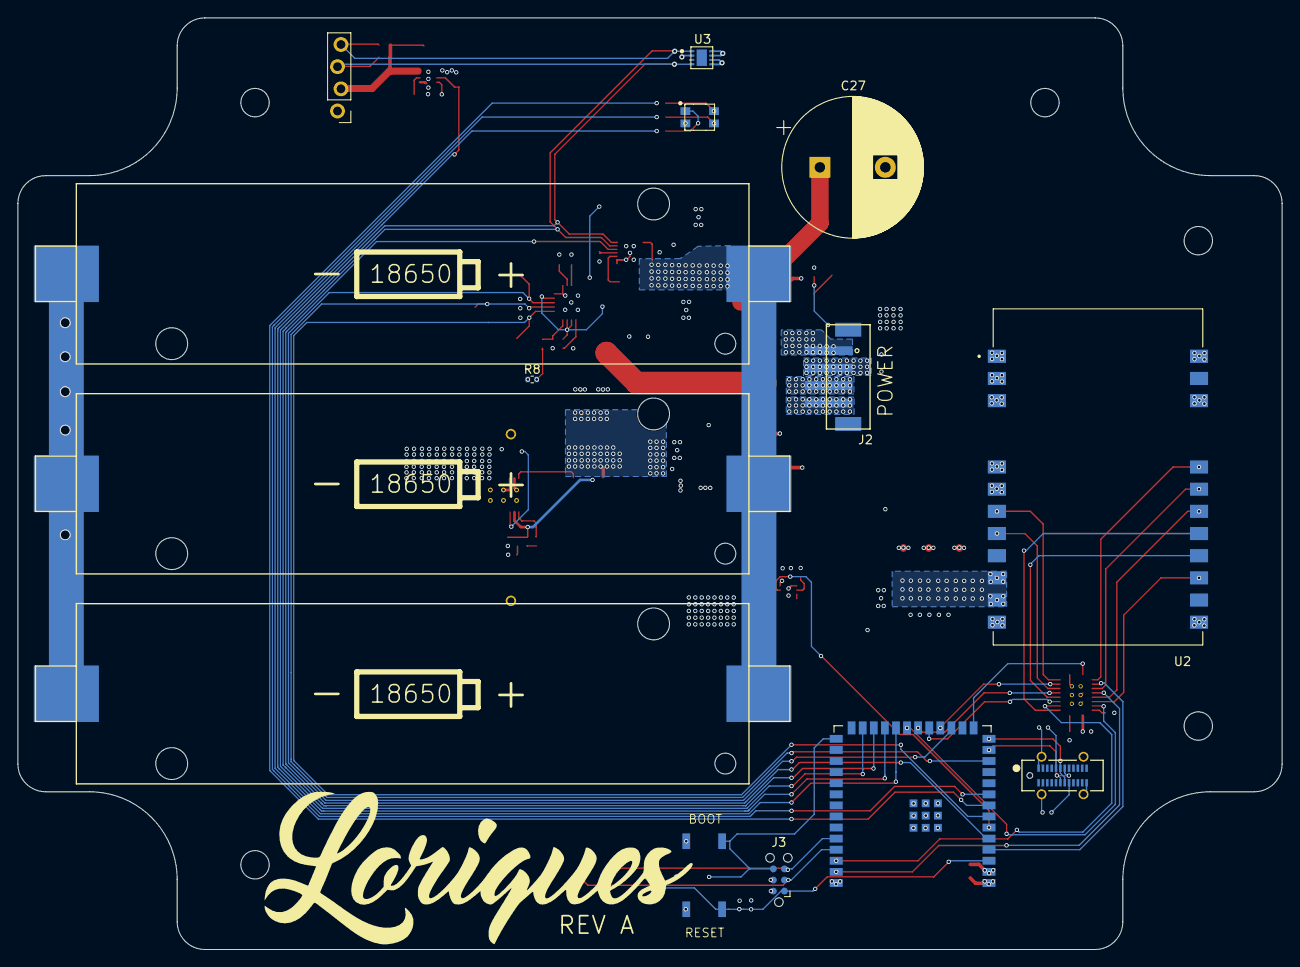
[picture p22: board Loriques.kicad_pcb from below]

Board: 6 copper layers, 144.8 x 106.7 mm, 121 parts (15 on the bottom side), 72 nets.

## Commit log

2025-07-11 fixed up silk screen text sizes, board outline and mounting holes
    [AutoNode.kicad_pcb]
2025-07-11 name change to Loriques
    [Loriques.kicad_pcb, Loriques.kicad_sch, mcu.kicad_sch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]
2025-07-11 added logo to schematic sheets
    [Loriques.kicad_sch, mcu.kicad_sch, power_input.kicad_sch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]
2025-07-11 added lots of 3d models
    [1042.STEP, B3B-PH-SM4-TB.STEP, B4B-PH-SM4-TB.STEP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]
2025-07-11 more 3D parts. changed out the temp/humidity sensor for an instock one
    [DEF0008A.stp, DSG0008A.stp, Loriques.kicad_pcb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]
2025-07-11 lots of routing, tweaking placement. adding courtyards
    [IHLP2525CZ.step, LP38693MP-ADJ_NOPB.step, Loriques.kicad_pcb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]
2025-07-12 initial routing done!
    [CS1213AG-tr.stp, LTC3113IDHD_TRPBF.step, Loriques.kicad_pcb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]
2025-07-12 some DRC fixing
    [Loriques.kicad_pcb, mcu.kicad_sch]
2025-07-12 silkscreen cleanup. add readme.
    [Loriques.kicad_pcb]
